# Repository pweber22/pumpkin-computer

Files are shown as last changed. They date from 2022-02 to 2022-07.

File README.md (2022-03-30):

# pumpkin-computer
Computer for dropping a pumpkin from a moving airplane to hit a target. Computer calculates when and where to drop, then guides the plane to that location and times the drop.\
Uses a Teensy 4.0 and a [PA1010D GPS breakout from Adafruit](https://learn.adafruit.com/adafruit-mini-gps-pa1010d-module).\
Display is a 32x128 ssd1306 OLED display from [Amazon](https://smile.amazon.com/dp/B08L7QW7SR?ref=ppx_yo2_dt_b_product_details&th=1).\
Schematic and potential pcb layout Eagle files are in the PumpkinSchematics directory, and the arduino code is in the PumpkinComputer directory.\
Uses Wire, Adafruit_GFX, Adafruit_SSD1306, and Adafruit_GPS Libraries.

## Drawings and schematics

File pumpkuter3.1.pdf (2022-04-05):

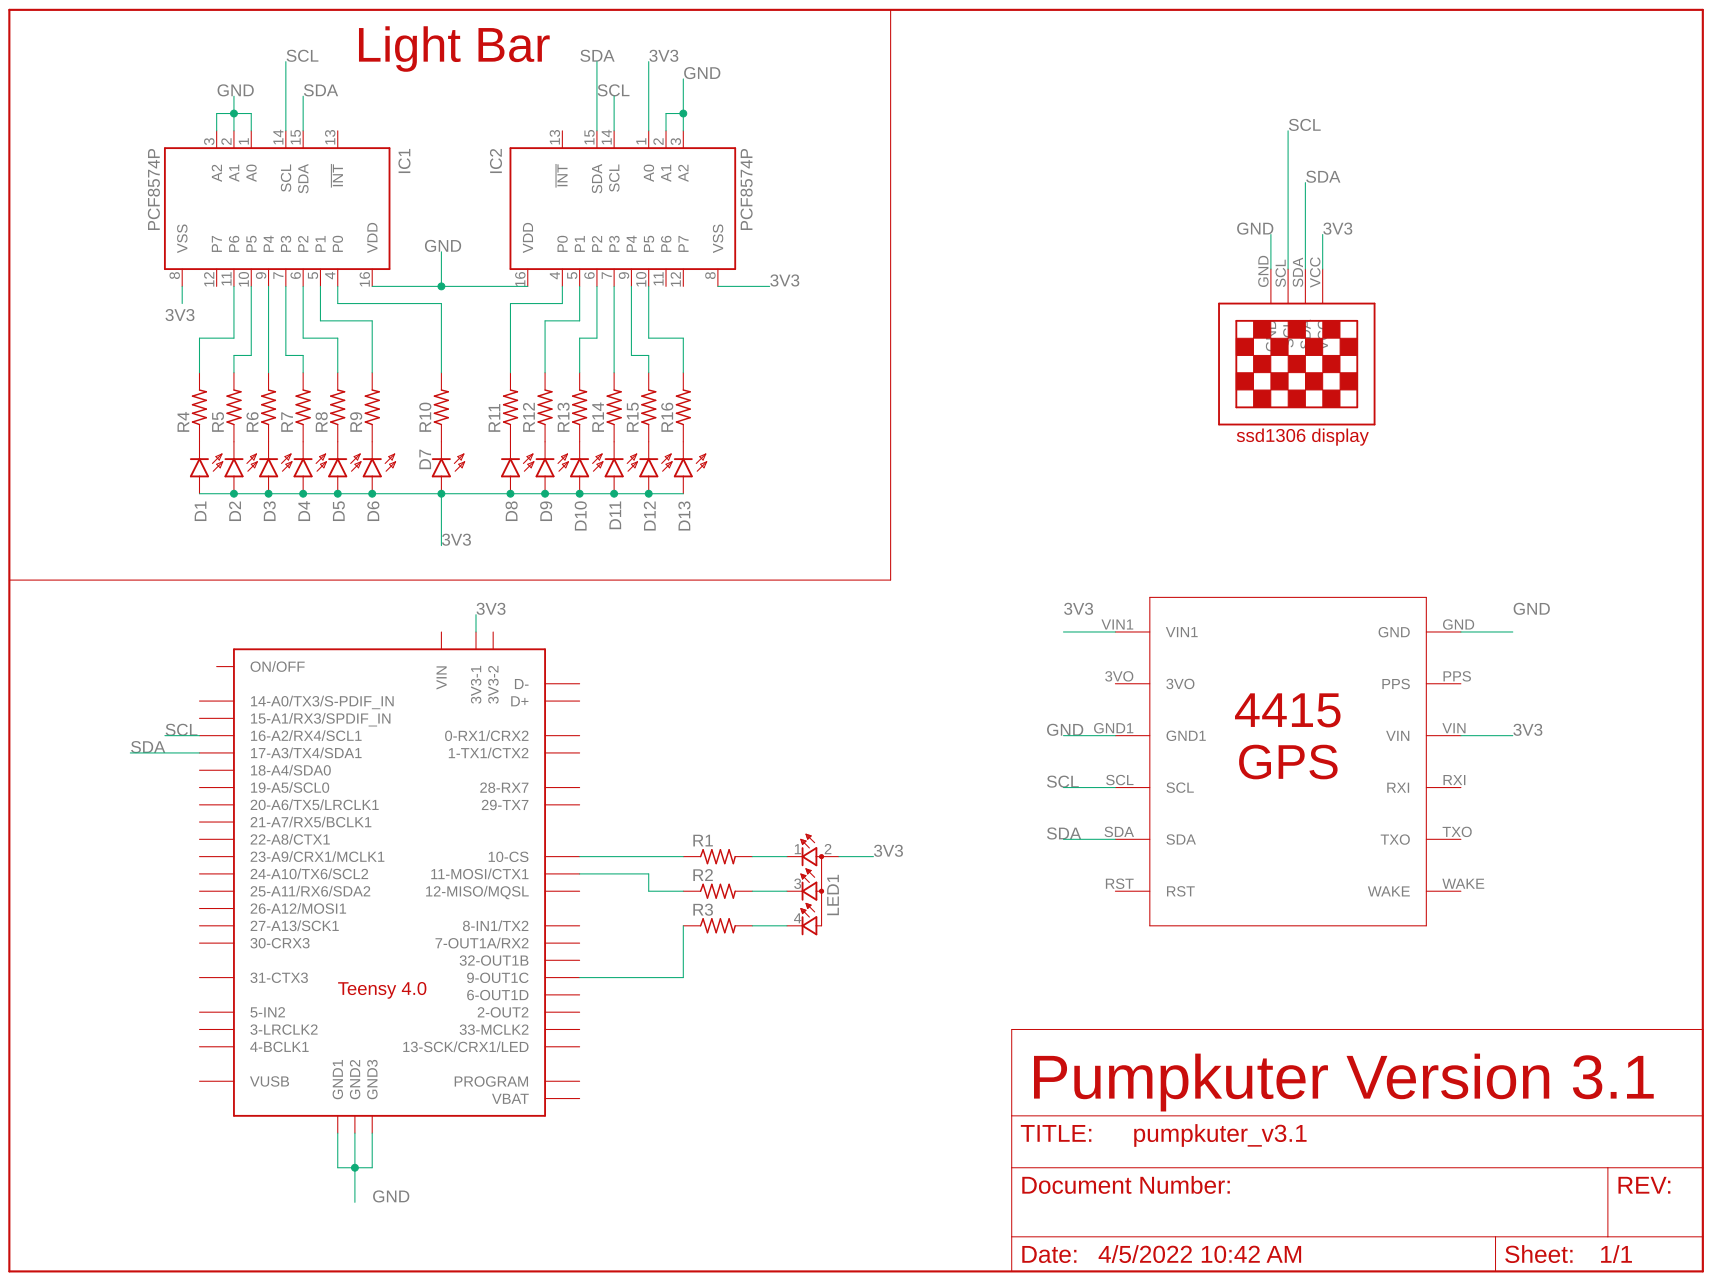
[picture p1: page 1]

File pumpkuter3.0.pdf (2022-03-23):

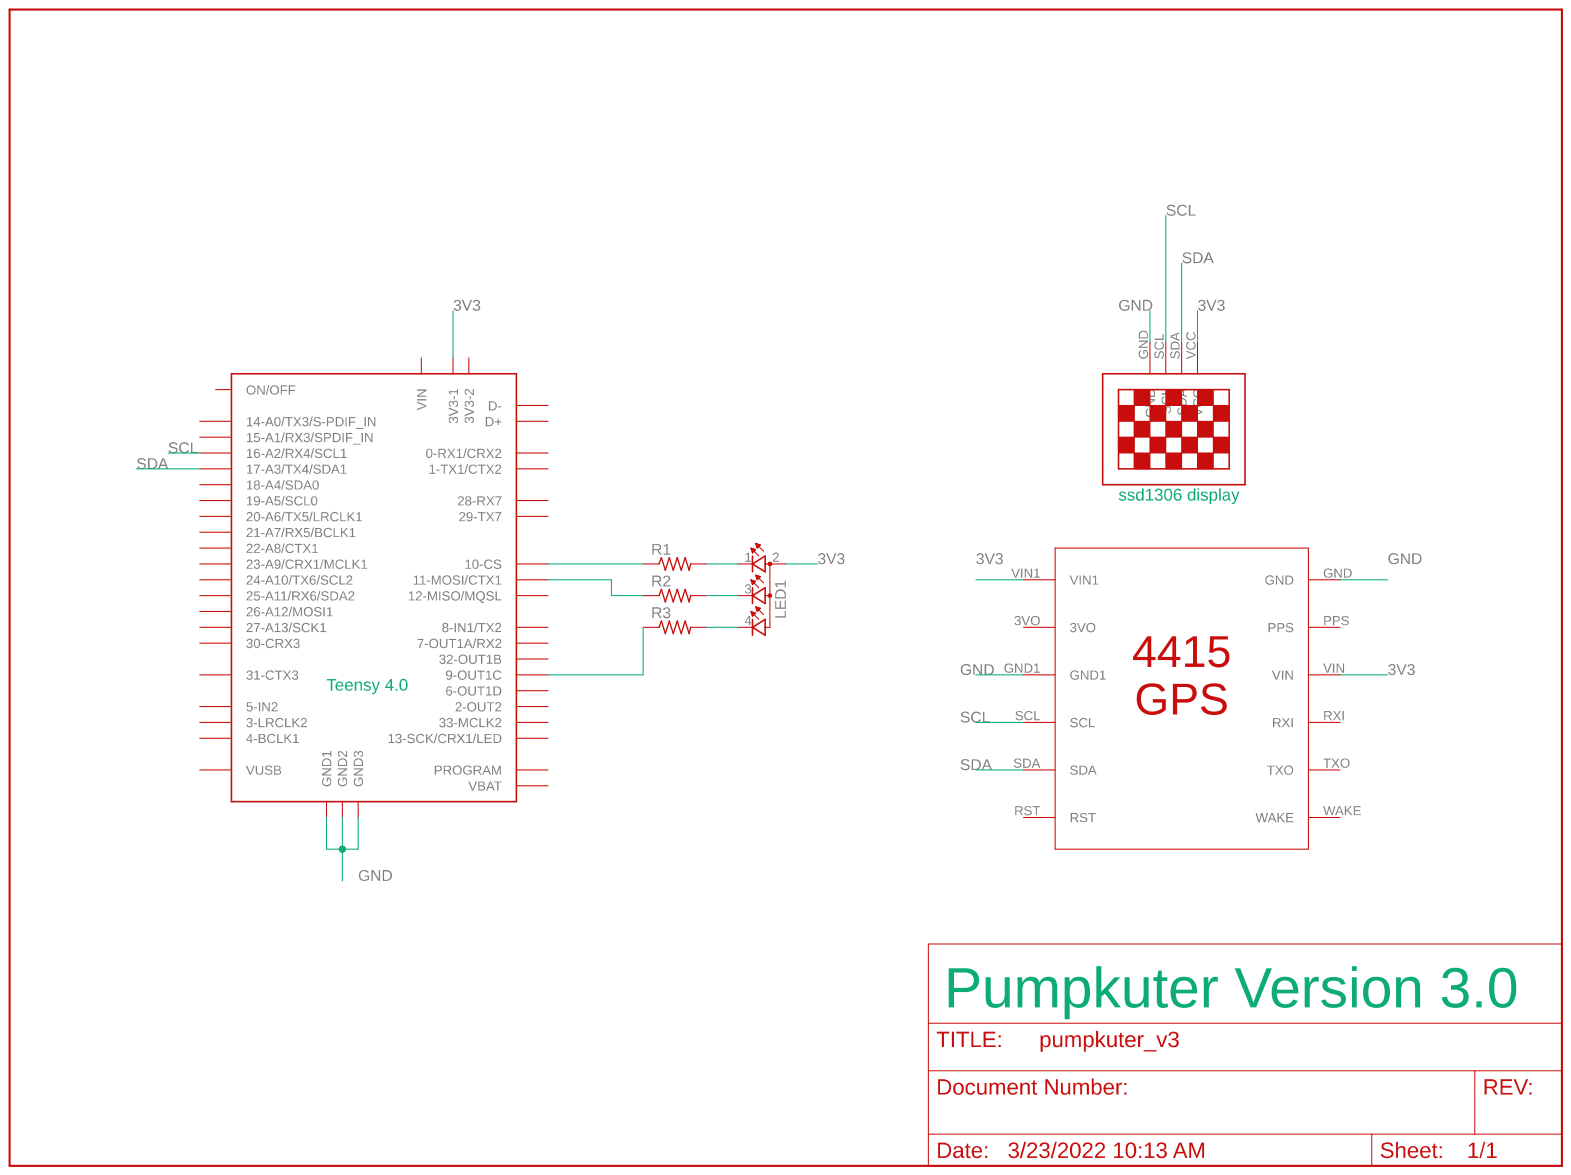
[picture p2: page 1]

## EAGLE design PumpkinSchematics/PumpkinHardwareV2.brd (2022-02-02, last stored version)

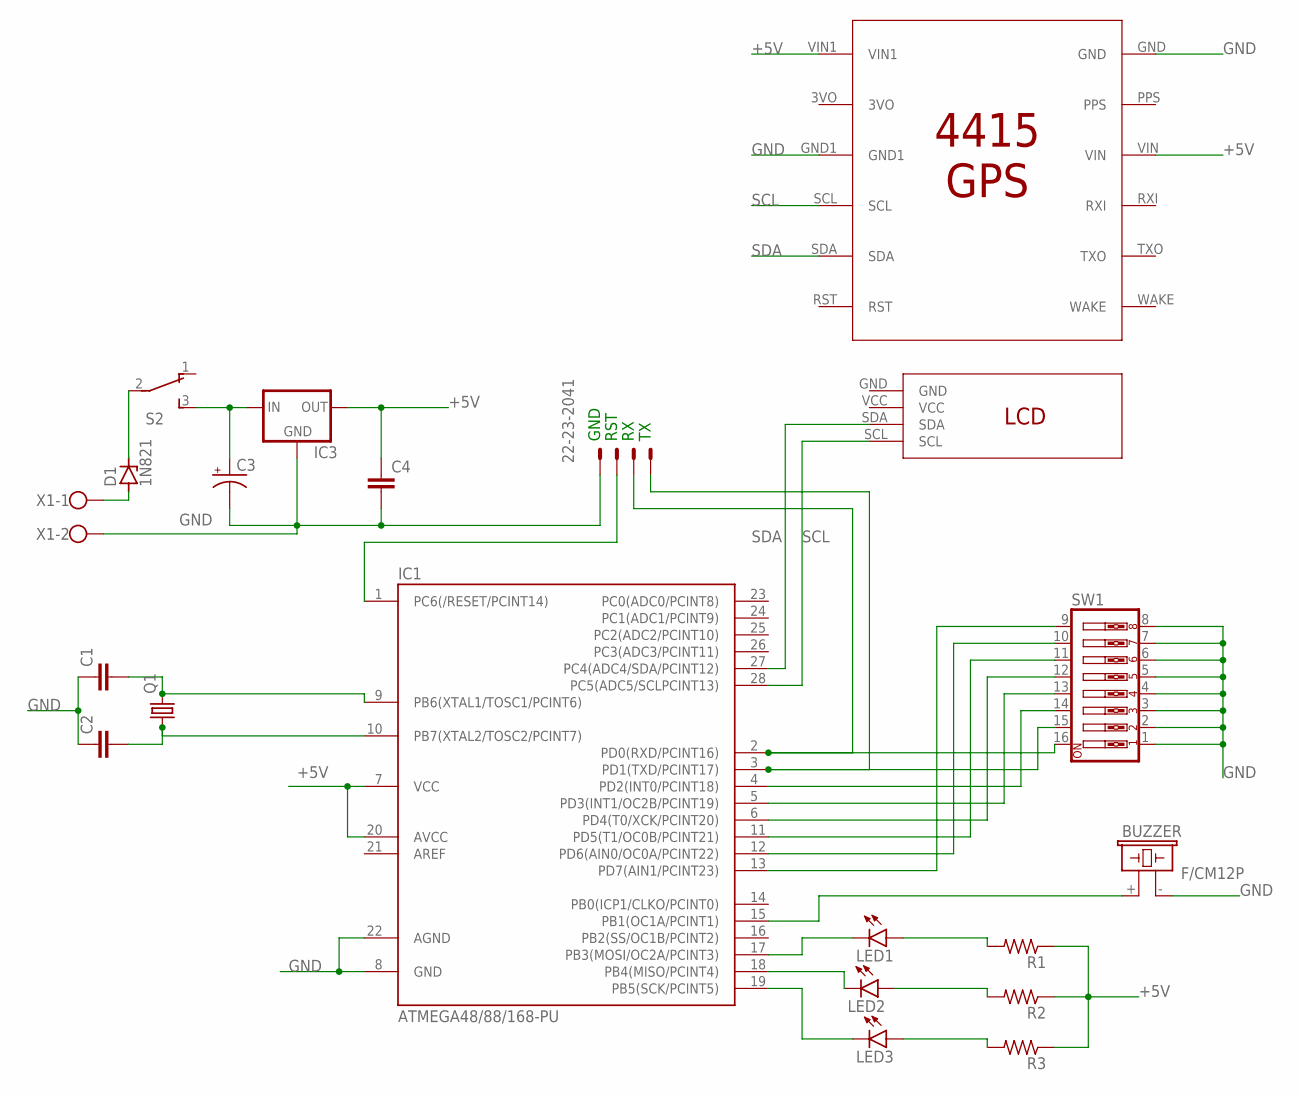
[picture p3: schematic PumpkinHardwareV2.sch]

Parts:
BUZZER: F/CM12P
C1, C2, C4: C2.5/2; C2.5-2
C3: CPOL-USE3.5-8; E3,5-8
D1: 1N821; DO35Z10
GPS: 4415
IC1: ATMEGA48/88/168-PU; DIL28-3
IC3: 78XXL
LED1: TLLG4400; LED3MM
LED2: TLLY4400; LED3MM
LED3: TLLR4400; LED3MM
Q1: CRYSTALHC49S; HC49/S
R1, R2, R3: R-US_0207/10; 0207/10
S2: TL36PO; TL3XPO
SW1: SW_DIP-8; EDG-08
U$1: I2C_LCD
X1: W237-102
X2: 22-23-2041

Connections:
+5V: C4.1, GPS.VIN, GPS.VIN1, IC1.7 (VCC), IC1.20 (AVCC), IC3.OUT, R1.1, R2.1, R3.1
GND: BUZZER.- (2), C1.1, C2.1, C3.-, C4.2, GPS.GND, GPS.GND1, IC1.8 (GND), IC1.22 (AGND), IC3.GND, SW1.1, SW1.2, SW1.3, SW1.4, SW1.5, SW1.6, SW1.7, SW1.8, X1.2, X2.1
unnamed: LED1.A, R1.2
unnamed: IC1.18 (PB4(MISO/PCINT4)), LED2.K (C)
unnamed: IC1.19 (PB5(SCK/PCINT5)), LED3.K (C)
unnamed: LED2.A, R2.2
unnamed: LED3.A, R3.2
unnamed: IC1.17 (PB3(MOSI/OC2A/PCINT3)), LED1.K (C)
unnamed: IC1.13 (PD7(AIN1/PCINT23)), SW1.9
unnamed: IC1.12 (PD6(AIN0/OC0A/PCINT22)), SW1.10
unnamed: IC1.11 (PD5(T1/OC0B/PCINT21)), SW1.11
unnamed: IC1.6 (PD4(T0/XCK/PCINT20)), SW1.12
unnamed: IC1.5 (PD3(INT1/OC2B/PCINT19)), SW1.13
unnamed: IC1.4 (PD2(INT0/PCINT18)), SW1.14
unnamed: IC1.3 (PD1(TXD/PCINT17)), SW1.15, X2.4
unnamed: D1.C, S2.2
unnamed: C2.2, IC1.10 (PB7(XTAL2/TOSC2/PCINT7)), Q1.1
unnamed: C1.2, IC1.9 (PB6(XTAL1/TOSC1/PCINT6)), Q1.2
unnamed: D1.A, X1.1
unnamed: C3.+, IC3.IN, S2.3 (S)
unnamed: BUZZER.+ (1), IC1.15 (PB1(OC1A/PCINT1))
unnamed: IC1.1 (PC6(/RESET/PCINT14)), X2.2
unnamed: IC1.2 (PD0(RXD/PCINT16)), SW1.16, X2.3
SCL: GPS.SCL, IC1.28 (PC5(ADC5/SCLPCINT13)), U$1.SCL
SDA: GPS.SDA, IC1.27 (PC4(ADC4/SDA/PCINT12)), U$1.SDA

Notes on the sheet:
GND
RST

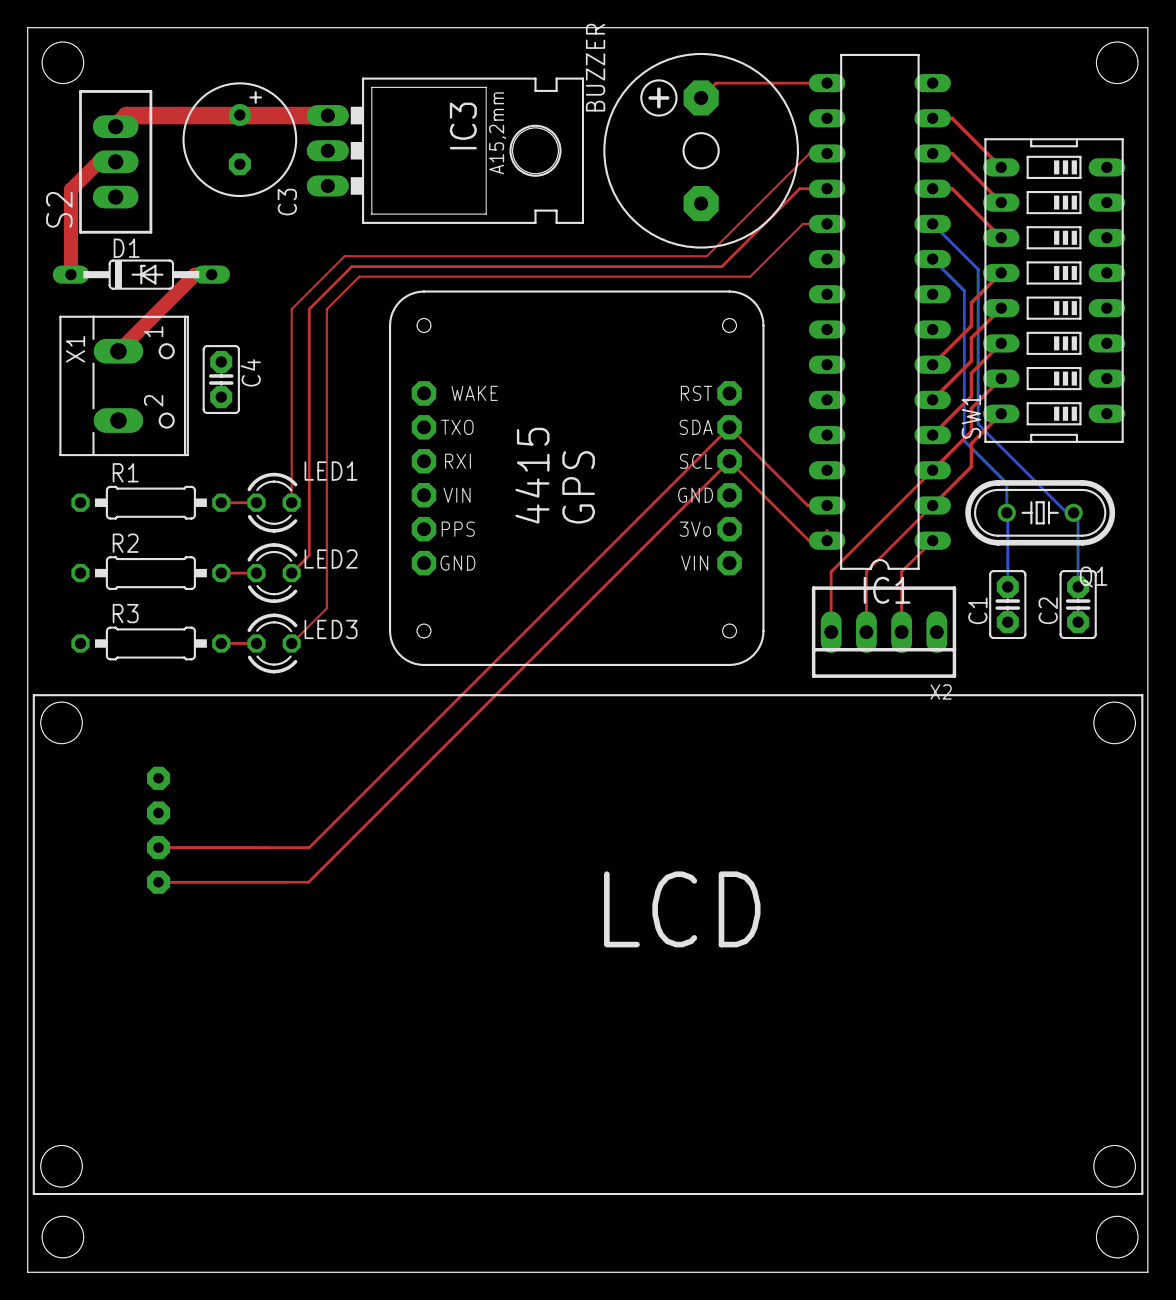
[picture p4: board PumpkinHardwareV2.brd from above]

Board: 2 copper layers, 80.8 x 89.8 mm, 21 parts (0 on the bottom side), 25 nets.

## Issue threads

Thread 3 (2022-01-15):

Guidance bar overflow

pweber22, 2022-01-15:
Due to the y>mx+b or y<mx+b comparison, a steep slope (flight path near due north or south) will likely result in overflow when even a small x is plugged in. This will cause an inaccurate error value to be displayed.
Potential solution: use a x=my+b form for bearings close to 180 or 0 deg

Closed 2022-03-22.

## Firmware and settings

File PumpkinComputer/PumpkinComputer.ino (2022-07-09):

#include <Wire.h>
#include <Adafruit_GFX.h>
#include <Adafruit_SSD1306.h>
#include <Adafruit_GPS.h>
#include "Display.h"
#include "Pumpkin.h"
#include "Target.h"
#include "Wind.h"

#define doLogging true

#define time_zone 19

const int ft_per_bar = 5;     //feet per light on the error bar
const int abort_threshold = 25;  //feet from flight path to trigger abort on entering terminal guidance

const uint8_t addr_left = 0x20;
const uint8_t addr_right = 0x24;

Adafruit_SSD1306 display(128, 32, &Wire1, 0);
Adafruit_GPS GPS(&Wire1);

unsigned int state;

uint8_t c;  //character for gps read buffer

//float pumpkin_cd=1.00; // coefficient of drag of the pumpkin
//float pumpkin_mass=0.830;  // mass of the pumpkin in kg
//float pumpkin_circumference=0.40;  // circumference of the pumpkin in meters

double plane_lat;
double plane_lon;
int alt_ft;
float vel_mph;

float bearingRad;
float bearingRadError;
float windX;
float windY;

long mPerLat;
long mPerLon;

float plane_ground_speed_mph;
float plane_gnd_speed;
int drop_height_ft;
float pumpkin_cross_section;
float err;

float time_step=0.01;

float dropX;
float dropY;
float pathX;
float pathY;
double m;
double b;

#define g -9.81 // acc from gravity
#define pi 3.14159265 // pi

float dropDistance;
int time_to_drop;
float drop_time;

void setup() {
  pinMode(9, OUTPUT);
  pinMode(10, OUTPUT);
  pinMode(11, OUTPUT);
  for(int i=0;i<8;i++){
    pinMode(i, INPUT_PULLUP); 
  }

  analogWrite(9, 200);
  analogWrite(10, 200); 
  analogWrite(11, 200);
  
  Serial.begin(115200);
  display.begin(SSD1306_SWITCHCAPVCC, 0x3c);
  display.clearDisplay();
  //display.drawBitmap(0, 0, image_data_frame000, 64, 32, 1);
  //display.display();
  pinMode(13, OUTPUT);
  
  GPS.begin(0x10);
  
  display.setTextColor(1);
  display.setCursor(0,0);
  display.write("NO GPS");
  display.display();

  while(!GPS.newNMEAreceived()){
    c=GPS.read();
  }
  GPS.sendCommand(PMTK_SET_NMEA_OUTPUT_RMCGGA);
  GPS.sendCommand(PMTK_API_SET_FIX_CTL_5HZ);
  GPS.sendCommand(PMTK_SET_NMEA_UPDATE_5HZ);

  for(int i=0; i<5; i++){
    while(!GPS.newNMEAreceived()){
      c=GPS.read();
    }
  }
  
  display.clearDisplay();
  display.setCursor(0,0);
  display.write(GPS.lastNMEA());
  display.display();
  getSetting();

  uint8_t bar = 0x01;
  //Light bar startup out solid
  while(bar<0xff){
    lightBar(bar, bar);
    bar = bar << 1;
    bar++;
    delay(100);
  }
  //light bar startup turn off from outside in
  for(uint8_t i=0xff; i>0x00; i=i>>1){
    lightBar(i, i);
    delay(100);
  }
  //light bar send lights from middle outward, stop at edges
  bar = 0x01;
  while(bar<0x80){
    lightBar(bar, bar);
    bar = bar << 1;
    delay(100);
  }
  delay(1000);

  // configure wind, convert to m/s and get x&y components
  float wind_speed=wind_speed_mph*0.44704;
  windX=sin(wind_dir*pi/180)*wind_speed;
  windY=cos(wind_dir*pi/180)*wind_speed;

  // calculate meters per degree latitude and longitude at target location
  bearingRad = bearing*pi/180;
  bearingRadError = (-bearing)+90;
  bearingRadError = bearingRadError*pi/180;
  float radLat=targetLat*pi/180;
  mPerLat = (111132.92-559.82*cos(2*radLat)+1.175*cos(4*radLat)-0.0023*cos(6*radLat));
  mPerLon = (111412.84*cos(radLat)-93.5*cos(3*radLat)+0.118*cos(5*radLat));


  
#if doLogging
  //Serial.println("hour,minute,second,state,fix,sats,latitude,longitude,altft,hdg,vel_mph,error,timetodrop,tgtbearing,dropDistance");
#endif
  setState_aqi();
}

void loop() {
  //update GPS
  while(!GPS.newNMEAreceived()){
    c=GPS.read();
   }
  GPS.parse(GPS.lastNMEA());
  
  //get plane coordinates in decimal degrees
  plane_lat=(int)(GPS.latitude/100);
  plane_lat+=fmod(GPS.latitude, 100)/60;
  plane_lon=(int)(GPS.longitude/100);
  plane_lon+=fmod(GPS.longitude, 100)/60;
  if(GPS.lon == 'W')
    plane_lon = -plane_lon;

  //get plane coordinates in local xy system
  float planeX=mPerLon*(plane_lon-targetLon);
  float planeY=mPerLat*(plane_lat-targetLat);

  if(state==0){
    char msg[9];
    for(int i=128; i>-65;i-=6){
      for(int j=0; j<6; j+=2){
        display.clearDisplay();
        display.drawBitmap(i-j, 0, image_data_frame000, 64, 32, 2);
        display.setCursor(80,25);
        sprintf(msg, "%02d:%02d:%02d", (GPS.hour+time_zone)%24, GPS.minute, GPS.seconds);
        display.write(msg);
        display.display();
        delay(20);
      }
      while(!GPS.newNMEAreceived())
        c=GPS.read();
      GPS.parse(GPS.lastNMEA());
    }
    for(int i=0; i<10; i++){
      while(!GPS.newNMEAreceived()){
        c=GPS.read();
      }
      GPS.parse(GPS.lastNMEA());
      display.clearDisplay();
      display.setCursor(80,25);
      sprintf(msg, "%02d:%02d:%02d", (GPS.hour+time_zone)%24, GPS.minute, GPS.seconds);
      display.write(msg);
      display.display();
      #if doLogging
      SerialLog();
      #endif
    }
    if(GPS.fix){
      if(digitalRead(0))
        setState_targeting();
      else
        setState_run();
    }
  }

  if(state==1){

    //update ground speed and agl height with new gps data
    plane_ground_speed_mph=(GPS.speed*1.151);
    drop_height_ft=(GPS.altitude*3.28-targetAlt_ft);

    //run simulation and update drop coordinates
    dropSim();

    //calculate flight path (y=mx+b in local coordinates, target is origin)
    m=tan(-(bearing+90.0)*pi/180.0);
    b=dropY-m*dropX;

    //calculate nearest point along planned flight path
    pathX=(abs(((-m)*planeX+planeY)-b))/sqrt(sq(m)+1);
    pathY=m*pathX+b;

    //calculate distance to flight path
    err=abs(cos(bearingRadError) * (dropY - planeY) - (sin(bearingRadError)*(dropX - planeX)));
    //err=sqrt(sq(pathX-planeX)+sq(pathY-planeY));
    if(bearing <180){
      if(planeY>m*planeX+b)
        err*=-1;
    }
    else{
      if(planeY<m*planeX+b)
        err*=-1;
    }
    err*= 3.281;  //convert error to feet

    //display error on light bar
    bar_show_error(err);

    //calculate time to drop
    dropDistance=sqrt(sq(planeX-dropX)+sq(planeY-dropY));
    if(plane_gnd_speed>1)
      time_to_drop=dropDistance/plane_gnd_speed;
    else time_to_drop=599;
    if(time_to_drop > 599) time_to_drop=599;

    //send new data to display and serial

    #if doLogging
      SerialLog();
    #endif
    
    display.clearDisplay();
    display.setTextSize(1);
    display.setTextColor(1);
    display.setCursor(0,0);
    char buf[85];
    sprintf(buf, "spd:%3dmph alt:%4dft\nbng:%03d       sats:%2d\nhdg:%03d\nTime: %1d:%02d  err:%5d",
            (int)(GPS.speed*1.151), (int)(GPS.altitude*3.28)-targetAlt_ft, bearing, GPS.satellites,
            (int)GPS.angle, time_to_drop/60, time_to_drop%60, (int)err);
    display.print(buf);
//    display.print(plane_lat,6);
//    display.setCursor(0,8);
//    display.print(plane_lon,6);
//    display.setCursor(0,16);
//    display.print(GPS.altitude*3.28);
//    display.print(" ft");
//    display.setCursor(0,24);
//    display.print(GPS.speed*1.151);
//    display.print(" mph");
//    display.setCursor(80,0);
//    display.print("hdg: ");
//    display.print((int)GPS.angle);
    display.display();

    if(time_to_drop<=3.0){
      setState_terminal(dropDistance);
    }

    
    if(digitalRead(0)==LOW)
      setState_targeting();
    
    if(!GPS.fix)
      setState_aqi();
  } //if(state==1)

  while(state==2){
    float terminal_count=drop_time-millis();
    long gps_timer=millis();
    

    // Update gps for error bar every 200 ms
    while(!GPS.newNMEAreceived()){
      c=GPS.read();
    }
    GPS.parse(GPS.lastNMEA());
    
    //get plane coordinates in decimal degrees
    plane_lat=(int)(GPS.latitude/100);
    plane_lat+=fmod(GPS.latitude, 100)/60;
    if(GPS.lat == 'S') plane_lat = -plane_lat;
    plane_lon=(int)(GPS.longitude/100);
    plane_lon+=fmod(GPS.longitude, 100)/60;
    if(GPS.lon == 'W') plane_lon = -plane_lon;
    
    //get plane coordinates in local xy system
    float planeX=mPerLon*(plane_lon-targetLon);
    float planeY=mPerLat*(plane_lat-targetLat);
    
    //calculate nearest point along planned flight path
    pathX=(m*(((1/m)*planeX+planeY)-b))/sq(m)+1;
    pathY=m*pathX+b;

    //calculate distance to flight path
    err=abs(cos(bearingRadError) * (dropY - planeY) - (sin(bearingRadError)*(dropX - planeX)));
    //err=(long)sqrt(sq(pathX-planeX)+sq(pathY-planeY));
    if(bearing <180){
      if(planeY>m*planeX+b)
        err*=-1;
    }
    else{
      if(planeY<m*planeX+b)
        err*=-1;
    }
    err*= 3.281;  //convert error to feet
    SerialLog();
    bar_show_error(err);  //display error on light bar

    display.clearDisplay();
    display.setTextSize(4);
    while(millis()-gps_timer<200){
      terminal_count=drop_time-millis();
      Serial.println("TIMR,"+String(float(terminal_count/1000)));
      display.clearDisplay();
      display.setCursor(0,0);
      display.print(float(terminal_count/1000), 3);
      display.display();
      if(terminal_count<=0) 
        setState_drop();
    }
    display.setTextSize(1);
  }

  if(state==3){
    SerialLog();
    display.clearDisplay();
    display.setCursor(0,0);
    display.setTextSize(4);
    display.print("DROP");
    display.display();
    
  }

  if(state==5){
    plane_lat=(int)(GPS.latitude/100);
    plane_lat+=fmod(GPS.latitude, 100)/60;
    if(GPS.lat == 'S') plane_lat = -plane_lat;
    plane_lon=(int)(GPS.longitude/100);
    plane_lon+=fmod(GPS.longitude, 100)/60;
    if(GPS.lon == 'W') plane_lon = -plane_lon;
    
    display.clearDisplay();
    display.setCursor(0,0);
    display.print("Lat: ");
    display.print(plane_lat, 6);
    display.print("\nLon: ");
    display.print(plane_lon, 6);
    display.print("\nAlt: ");
    display.print(GPS.altitude*3.28);
    display.print("ft");
    display.print("\nSats: ");
    display.print(GPS.satellites);
    display.display();

    if(digitalRead(0)==HIGH) setState_run();
    if(!GPS.fix) setState_aqi();
  }
}

void setState_aqi(){
  state=0;
  analogWrite(9, 256);
  analogWrite(10, 256);
  analogWrite(11, 200);
  lightBar(0x40, 0x40);
}

void setState_run(){
  state=1;
  analogWrite(9,256);
  analogWrite(10,200);
  analogWrite(11,256);
  lightBar(0x00, 0x00);
}

void setState_terminal(float dist_to_drop){
  if(err > abort_threshold){
    setState_abort();
    return;
  }
  state=2;
  analogWrite(9, 256);
  analogWrite(10, 100);
  analogWrite(11, 100);
  //float dist_to_drop = sqrt(pow(planeX-dropX,2)+pow(planeY-dropY,2));
  drop_time=millis()+(1000*dist_to_drop/plane_gnd_speed);
}

void setState_drop(){
  state=3;
  analogWrite(9, 256);
  analogWrite(10, 100);
  analogWrite(11, 256);
  lightBar(0xff, 0xff);

  //serial log drop data
  if(0){
    //get plane coordinates in decimal degrees
    plane_lat=(int)(GPS.latitude/100);
    plane_lat+=fmod(GPS.latitude, 100)/60;
    plane_lon=(int)(GPS.longitude/100);
    plane_lon+=fmod(GPS.longitude, 100)/60;
    if(GPS.lon == 'W')
      plane_lon = -plane_lon;
    
    //get plane coordinates in local xy system
    float planeX=mPerLon*(plane_lon-targetLon);
    float planeY=mPerLat*(plane_lat-targetLat);
  
    //update ground speed and agl height with new gps data
    float final_ground_speed_mph=(GPS.speed*1.151);
    int final_drop_height=(GPS.altitude*3.28-targetAlt_ft);
    
    String logBuffer="DROP,";
    logBuffer+=String(GPS.hour)+',';
    logBuffer+=String(GPS.minute)+',';
    logBuffer+=String(GPS.seconds)+',';
    logBuffer+=String(state)+',';
    logBuffer+=String(GPS.fix)+',';
    logBuffer+=String(GPS.satellites)+',';
    logBuffer+=String(plane_lat,6)+',';
    logBuffer+=String(plane_lon,6)+',';
    logBuffer+=String(drop_height_ft)+',';
    logBuffer+=String((int)GPS.angle)+',';
    logBuffer+=String(plane_ground_speed_mph)+',';
    logBuffer+=String(err)+',';
    logBuffer+=String(time_to_drop)+',';
    logBuffer+=String(bearing)+',';
    logBuffer+=String(planeX-dropX)+',';
    logBuffer+=String(planeY-dropY)+',';
    logBuffer+=String(final_ground_speed_mph)+',';
    logBuffer+=String(final_drop_height);
    Serial.println(logBuffer);
  }
}

void setState_abort(){
  state = 4;
  analogWrite(9, 256);
  analogWrite(10, 256);
  analogWrite(11, 100);
  bool rst = digitalRead(0);
  display.clearDisplay();
  display.setCursor(0,0);
  display.print("Abort! \nerr at ");
  display.print(dropDistance*3.28);
  display.print("ft:");
  display.print(err);
  display.print("ft");
  display.print("\ntoggle switch 1 \nto reset");
  display.display();
  while(digitalRead(0) == rst){
    lightBar(0xaa, 0xaa);
    delay(500);
    lightBar(0x55, 0x55);
    delay(500);
  }
  setState_run();
}

void setState_targeting(){
  state = 5;
  lightBar(0x03, 0x03);
  analogWrite(9, 200);
  analogWrite(10, 256);
  analogWrite(11, 256);
}

void dropSim(){
  analogWrite(11,200);
  plane_gnd_speed=plane_ground_speed_mph*0.44704;
  float drop_height=drop_height_ft*0.3048;
  
  //initialize sim variables, orient plane in local coordinate system
  float sim_time=0.0;
  float pumpkin_x=0.0;
  float pumpkin_y=0.0;
  float pumpkin_z=drop_height;
  float pumpkin_x_gnd_speed=sin(bearingRad)*plane_gnd_speed;
  float pumpkin_y_gnd_speed=cos(bearingRad)*plane_gnd_speed;
  float pumpkin_y_air_speed=pumpkin_y_gnd_speed+windY;
  float pumpkin_x_air_speed=pumpkin_x_gnd_speed+windX;
  float pumpkin_vertical_speed=0.0;

  float drag_z;
  float drag_y;
  float drag_x;
  
  while(pumpkin_z>0.0){
    sim_time+=time_step;

    drag_z=pumpkin_cd*pumpkin_cross_section*air_density*pow(pumpkin_vertical_speed,2)/2;
    pumpkin_vertical_speed+=(g*time_step)+(drag_z/pumpkin_mass)*time_step;
    pumpkin_z+=pumpkin_vertical_speed*time_step;

    drag_y=pumpkin_cd*pumpkin_cross_section*air_density*pow(pumpkin_y_air_speed,2)/2;
    pumpkin_y_gnd_speed-=(drag_y/pumpkin_mass)*time_step;
    pumpkin_y+=pumpkin_y_gnd_speed*time_step;
    pumpkin_y_air_speed=pumpkin_y_gnd_speed+windY;

    drag_x=pumpkin_cd*pumpkin_cross_section*air_density*pow(pumpkin_x_air_speed,2)/2;
    pumpkin_x_gnd_speed+=(drag_x/pumpkin_mass)*time_step;
    pumpkin_x+=pumpkin_x_gnd_speed*time_step;
    pumpkin_x_air_speed=pumpkin_x_gnd_speed+windX;
  }
  dropX=-pumpkin_x;
  dropY=-pumpkin_y;
  analogWrite(11,256);
}

void SerialLog(){
  String logBuffer="FDAT,";
  logBuffer+=String(GPS.hour)+',';
  logBuffer+=String(GPS.minute)+',';
  logBuffer+=String(GPS.seconds)+',';
  logBuffer+=String(state)+',';
  logBuffer+=String(GPS.fix)+',';
  logBuffer+=String(GPS.satellites)+',';
  logBuffer+=String(plane_lat,6)+',';
  logBuffer+=String(plane_lon,6)+',';
  logBuffer+=String(drop_height_ft)+',';
  logBuffer+=String((int)GPS.angle)+',';
  logBuffer+=String(plane_ground_speed_mph)+',';
  logBuffer+=String(err)+',';
  logBuffer+=String(time_to_drop)+',';
  logBuffer+=String(bearing)+',';
  logBuffer+=String((int)dropDistance);
  Serial.println(logBuffer);
}

void getSetting(){
  byte upper=0;
  for(int i=0; i<4; i++){
    upper=upper << 1;
    upper+=1 ^ digitalRead(i);
  }
  byte lower=0;
  for(int i=4; i<8; i++){
    lower=lower << 1;
    lower+=1 ^ digitalRead(i);
  }

  wind_speed_mph=upper;

  wind_dir=30*lower;
  
  //display.clearDisplay();
  display.setCursor(0,17);
  display.print("wind speed: ");
  display.print(wind_speed_mph);
  display.setCursor(0,24);
  display.print("wind dir: ");
  display.print(wind_dir);
  display.display();
}

void lightBar(byte left, byte right){
  left = ~left;
  right = ~right;
  Wire1.beginTransmission(addr_left);
  Wire1.write(left);
  Wire1.endTransmission();
  Wire1.beginTransmission(addr_right);
  Wire1.write(right);
  Wire1.endTransmission();
}

void bar_show_error(int error){  //display error on bar based on error number
    int err_scaled = abs(err/ft_per_bar);
    uint8_t bar = 0x01 << err_scaled;
    if(err_scaled != 0){
      bar-=1;
      bar <<=1;
    }
    if(err<ft_per_bar) lightBar(bar, 0x00);
    else lightBar(0x00, bar);
}

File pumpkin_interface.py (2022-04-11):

import serial
import time
import tkinter as tk
import sys
import tkinter.font
from PIL import Image, ImageTk
import logging

logging.getLogger('root').setLevel('INFO')

SERIALPORT='COM7'
feet_per_division = 3

def on_closing():
    #raise SystemExit
    print("exit")
    window.destroy()

def fmat(tgt):
    tgt.configure(font=('Helvetica', int(textSize), 'bold'), bg=bgnd, fg=fgnd, highlightbackground='#ddd', highlightthickness=1)

ttd_precise = False

#fnt = "Comic Sans MS"
bgnd = '#026'
fgnd = 'white'
vpad = 5
hpad = 15
window_open=True

degree_sign = u'\N{DEGREE SIGN}'

last_state = 0

root = tk.Tk()
root.title("Pumpkuter v3.1")
window = tk.Frame(master=root)
window.pack(side="top", fill="x", expand=False)
#window.configure(bg='green2')
window.configure(bg='#026')

frm_bar = tk.Frame(master=root)
frm_bar.pack(side="top", fill="both", expand=True)
frm_bar.configure(bg='green2')

lbl_test=tk.Label(master=window, text='No Serial Connection on '+SERIALPORT, font=('Helvetica', 50), bg='red')
lbl_test.grid(row=0, column=0)

connection=False
while(not connection):
    try:
        pumpkuter = serial.Serial(port=SERIALPORT, baudrate=115200, timeout=.1)
        connection = True
        lbl_test.destroy()
        logging.info("Connected to Pumpkuter")
    except serial.SerialException:
        root.update_idletasks()
        root.update()
        pass
        #print("Serial port not connected!")


for i in range(5):
    window.columnconfigure(i, weight=1, minsize=20)
    
window.rowconfigure(0,weight=0, minsize=30)

lbl_time = tk.Label(master=window, text='', padx=hpad, pady=vpad)
lbl_time.grid(row=0, column=0, sticky='nsew')
lbl_state = tk.Label(master=window, padx=hpad, pady=vpad, highlightbackground='#111', highlightthickness=2)
lbl_state.grid(row = 1, column=0, sticky='nsew')
lbl_latitude = tk.Label(master=window, padx=hpad, pady=vpad)
lbl_latitude.grid(row = 0, column=1, sticky='nsew')
lbl_longitude = tk.Label(master=window, padx=hpad, pady=vpad)
lbl_longitude.grid(row = 0, column=2, sticky='nsew')
lbl_sats = tk.Label(master=window, padx=hpad, pady=vpad)
lbl_sats.grid(row=2, column=0, sticky='nsew')
lbl_alt = tk.Label(master=window, padx=hpad, pady=vpad)
lbl_alt.grid(row=0, column=3, sticky='nsew')
lbl_vel = tk.Label(master=window, padx=hpad, pady=vpad)
lbl_vel.grid(row=0, column=4, sticky='nsew')
lbl_err = tk.Label(master=window, padx=hpad, pady=vpad)
lbl_err.grid(row=1, column=4, sticky='nsew')
lbl_ttd = tk.Label(master=window, padx=hpad, pady=vpad)
lbl_ttd.grid(row=2, column=4, sticky='nsew')
lbl_hdg = tk.Label(master=window, padx=hpad, pady=vpad)
lbl_hdg.grid(row=2, column=1, sticky='nsew')
lbl_bng = tk.Label(master=window, padx=hpad, pady=vpad)
lbl_bng.grid(row=1, column=1, sticky='nsew')
lbl_dist = tk.Label(master=window, padx=hpad, pady=vpad)
lbl_dist.grid(row=1, column=2, sticky='nsew')

can_bar = tk.Canvas(master=frm_bar)
can_bar.pack(fill='both', expand=True)
track = can_bar.create_line(100,200,200,50, fill='#999', width=6)
can_bar.configure(bg='blue')
plane_marker = can_bar.create_text(20, 20, text="^")


states=['AOS','RUN','TERM','SDWN', 'ABORT', 'TGT']
state_colors=['red','green','yellow','blue', 'orange', 'blue']

while window_open:
    textSize = window.winfo_width()/42
    fnt = ('Arial', int(textSize))
    #print(textSize)
    line = pumpkuter.readline().decode('utf-8')[:-2]
    
    if(line):
        
        if('TIMR' in line):
            time_to_drop=float(line.split(',')[1])
            ttd_precise=True
        
        if('DROP' in line):
            lbl_ttd.configure(bg='green')
            root.update()
            
            telem = line.split(',')
            hours = (int(telem[1]) + 19)%24
            minutes = int(telem[2])
            seconds = int(telem[3])
            time = '{:02}:{:02}:{:02} CST'.format(hours,minutes,seconds)
            state = int(telem[4])
            fix = int(telem[5])
            sats = int(telem[6])
            lat = float(telem[7])
            lon = float(telem[8])
            alt = int(telem[9])
            hdg = int(telem[10])
            vel = float(telem[11])
            err = int(telem[12])
            time_to_drop = int(telem[13])
            bearing = int(telem[14])
            plane_x_error = float(telem[15])
            plane_y_error = float(telem[16])
            final_gnd_spd = float(telem[17])
            final_drop_height = float(telem[18])
            
            
            drop_log_name='dropLogs/drop{:02}{:02}{:02}.txt'.format(hours,minutes,seconds)
            with open(drop_log_name, 'w') as f:
                f.write('Time: '+time)
                f.write('\nLat:{:08.5f}{:s}'.format(lat,degree_sign))
                f.write('\nLon:{:08.5f}{:s}'.format(lon,degree_sign))
                f.write('\nAlt:{:4d}ft'.format(alt))
                f.write('\nhdg {:03d}'.format(hdg))
                f.write('\nV:{:5.1f}mph'.format(vel))
                f.write('\nPath: {:03d}'.format(bearing))
                f.write('\nPlaneX-dropX: {:05.3f}m'.format(plane_x_error))
                f.write('\nPlaneY-dropY: {:05.3f}m'.format(plane_y_error))
                f.write('\nfinal_ground_speed: {:05.2f}mph'.format(final_gnd_spd))
                f.write('\nfinal_drop_height: {:04.1f}ft'.format(final_drop_height))
        
        if('FDAT' in line):
            telem = line.split(',')
            hours = (int(telem[1]) + 18)%24
            minutes = int(telem[2])
            seconds = int(telem[3])
            time = '{:02}:{:02}:{:02} CST'.format(hours,minutes,seconds)
            state = int(telem[4])
            fix = int(telem[5])
            sats = int(telem[6])
            lat = float(telem[7])
            lon = float(telem[8])
            alt = int(telem[9])
            hdg = int(telem[10])
            vel = float(telem[11])
            err = int(telem[12])
            if(not ttd_precise): time_to_drop = int(telem[13])
            bearing = int(telem[14])
            drop_dist = int(telem[15])
            
        time_bg = 'red'
        if time_to_drop <= 10:
            time_bg = 'yellow'
            if time_to_drop < 1:
                time_bg = 'green'
        
        err_scaled = err / feet_per_division
        err_pixels = err_scaled * can_bar.winfo_width()/15
        
        if(not state==last_state):
            logging.info("state changed to "+states[state])
            last_state=state
        
        lbl_time.configure(text=time)
        lbl_state.configure(text='State: '+states[state], bg=state_colors[state], font=fnt)
        lbl_latitude.configure(text='Lat:{:08.5f}{:s}'.format(lat,degree_sign))
        lbl_longitude.configure(text='Lon:{:08.5f}{:s}'.format(lon,degree_sign))
        lbl_sats.configure(text='Sats:{:d}'.format(sats))
        lbl_alt.configure(text='RAlt:{:4d}ft'.format(alt))
        lbl_hdg.configure(text='hdg {:03d}'.format(hdg))
        lbl_vel.configure(text='V:{:5.1f}mph'.format(vel))
        lbl_err.configure(text='err:{:4d}ft'.format(err))
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

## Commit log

2022-01-15 removed serial print statements
2022-01-27 added hardware schematics
    [PumpkinHardwareV2.brd, PumpkinHardwareV2.sch]
2022-02-02 added interrupt for simulation updates
    [PumpkinHardwareV2.brd]
2022-02-07 fixed interrupt system somewhat, doesn't always start properly
    [PumpkinComputer.ino]
2022-02-08 optimized display updates and update sim based on internal timer
2022-02-08 added gps check to startup and re-implemented interrupt based simulation updates
2022-02-09 added targeting mode to get target coordinates, activated by most significant bit switch after startup
2022-03-14 Updated software for Teensy processor and serial interface to computer for display
2022-03-21 fixed path error calculation
    [PumpkinComputer.ino]
2022-03-23 Added v3 schematic
    [PumpkinHardwareV2.brd, PumpkinHardwareV2.sch]
2022-04-05 Actually fixed error calculation (maybe)
    [PumpkinComputer.ino]
2022-04-05 Organized 3.1 schematic
2022-04-11 still working on error
    [PumpkinComputer.ino, pumpkin_interface.py]
